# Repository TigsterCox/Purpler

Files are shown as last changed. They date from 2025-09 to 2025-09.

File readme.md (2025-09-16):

This is my first keyboard i've ever made
I do NOT reccomend you attempt building it
the current QMK firmware is built for the *BODGED* PCB whereas the KiCad files are for a *FIXED* PCB though it shouldnt be too hard of a fix

<p align="center">
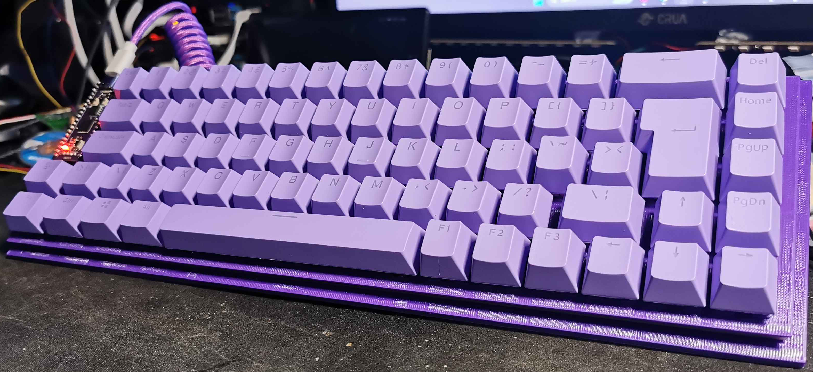
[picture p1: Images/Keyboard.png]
    
</p>

Its a 71 Key QWERTY UK ISO build based off of the Durgod Hades 69 ISO
my build uses AKKO Lavender Purple V3's and a generic keycap set from aliex
The RP2040 is a WEACT rpi 2040 as it is also purple (i think you get the theme here)
I use m2x6mm screws that are threaded into plastic, tho you can also adjust it for heatsets and shorter screws (which i plan on doing if i ever do a rebuild)

AGAIN, I DO NOT RECCOMEND BUILDING THIS

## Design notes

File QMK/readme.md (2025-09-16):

# purpler

purpler

*A short description of the keyboard/project*

* Keyboard Maintainer: [TigsterCox](https://github.com/TigsterCox)
* Hardware Supported: *The PCBs, controllers supported*
* Hardware Availability: *Links to where you can find this hardware*

Make example for this keyboard (after setting up your build environment):

    make purpler:default

Flashing example for this keyboard:

    make purpler:default:flash

See the [build environment setup](https://docs.qmk.fm/#/getting_started_build_tools) and the [make instructions](https://docs.qmk.fm/#/getting_started_make_guide) for more information. Brand new to QMK? Start with our [Complete Newbs Guide](https://docs.qmk.fm/#/newbs).

## Bootloader

Enter the bootloader in 3 ways:

* **Bootmagic reset**: Hold down the key at (0,0) in the matrix (usually the top left key or Escape) and plug in the keyboard
* **Physical reset button**: Briefly press the button on the back of the PCB - some may have pads you must short instead
* **Keycode in layout**: Press the key mapped to `QK_BOOT` if it is available

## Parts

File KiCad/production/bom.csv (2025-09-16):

Designator | Footprint | Quantity | Value | LCSC Part #
D1, D10, D11, D12, D13, D14, D15, D16, D17, D18, D19, D2, D20, D21, D22, D23, D24, D25, D26, D27, D28, D29, D3, D30, D31, D32, D33, D34, D35, D36, D37, D38, D39, D4, D40, D41, D42, D43, D44, D45, D46, D47, D48, D49, D5, D50, D51, D52, D53, D54, D55, D56, D57, D58, D59, D6, D60, D61, D62, D63, D64, D65, D66, D67, D68, D69, D7, D70, D71, D8, D9 | D_SOD-123 | 71 | Diode
S1, S10, S11, S12, S13, S15, S17, S18, S19, S2, S20, S21, S22, S23, S24, S25, S26, S27, S28, S3, S30, S32, S33, S34, S35, S36, S37, S38, S39, S4, S40, S41, S42, S43, S45, S47, S48, S49, S5, S50, S51, S52, S53, S54, S55, S56, S57, S59, S6, S60, S65, S66, S67, S68, S69, S7, S70, S8, S9 | Hotswap_MX_1.00u | 59 | Keyswitch
S14 | Hotswap_MX_2.00u | 1 | Keyswitch
S16, S44, S71 | Hotswap_MX_1.50u | 3 | Keyswitch
S29 | Hotswap_MX_ISOEnter | 1 | Keyswitch
S31, S58 | Hotswap_MX_1.75u | 2 | Keyswitch
S46, S61, S62, S63 | Hotswap_MX_1.25u | 4 | Keyswitch
S64 | Hotswap_MX_6.25u | 1 | Keyswitch
U1 | WeAct-RP2040-Pico | 1 | WeAct-RP2040-Pico

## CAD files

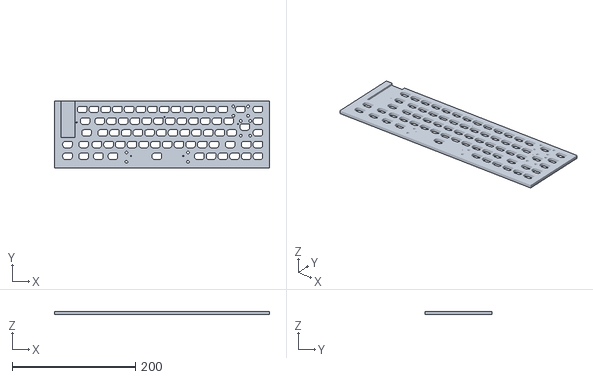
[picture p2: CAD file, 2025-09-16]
STL's/Underplate.stl
349.5 x 108.9 x 4.80

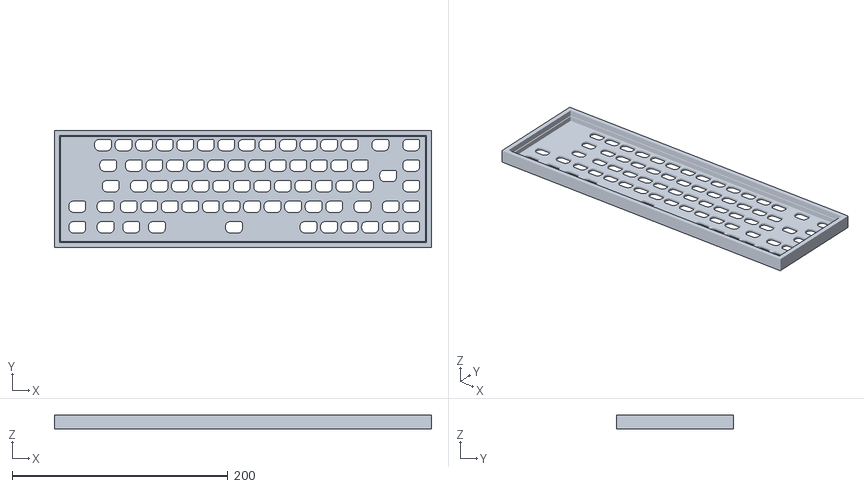
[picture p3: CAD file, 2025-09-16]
STL's/case.stl
349.5 x 108.9 x 13.1

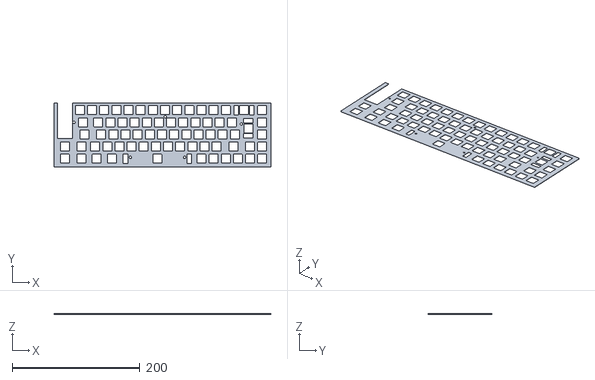
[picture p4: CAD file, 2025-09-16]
STL's/plate.stl
340.2 x 99.6 x 1.50

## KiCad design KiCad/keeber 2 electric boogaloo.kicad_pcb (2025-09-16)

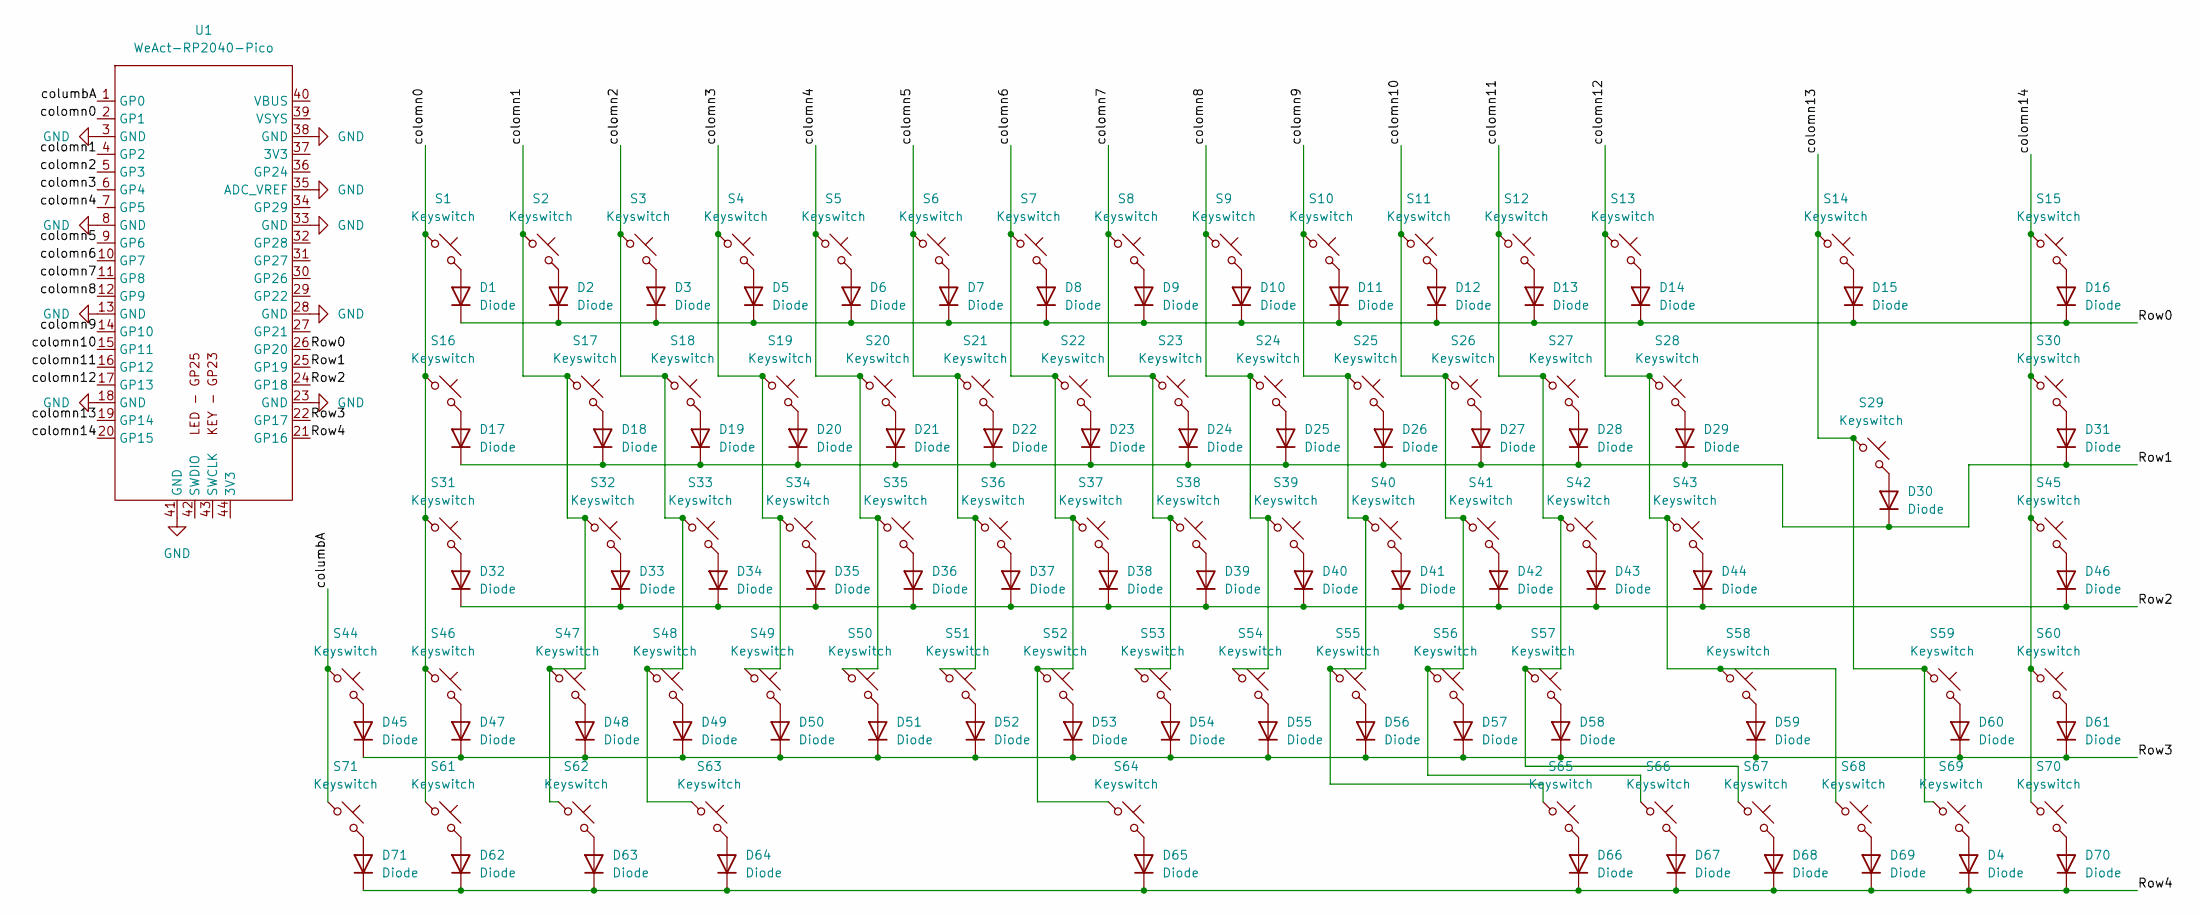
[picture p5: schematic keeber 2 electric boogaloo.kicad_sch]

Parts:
D1, D2, D3, D4, D5, D6, D7, D8, D9, D10, D11, D12, D13, D14, D15, D16, D17, D18, D19, D20, D21, D22, D23, D24, D25, D26, D27, D28, D29, D30, D31, D32, D33, D34, D35, D36, D37, D38, D39, D40, D41, D42, D43, D44, D45, D46, D47, D48, D49, D50, D51, D52, D53, D54, D55, D56, D57, D58, D59, D60, D61, D62, D63, D64, D65, D66, D67, D68, D69, D70, D71: Diode; D_SOD-123
S1, S2, S3, S4, S5, S6, S7, S8, S9, S10, S11, S12, S13, S15, S17, S18, S19, S20, S21, S22, S23, S24, S25, S26, S27, S28, S30, S32, S33, S34, S35, S36, S37, S38, S39, S40, S41, S42, S43, S45, S47, S48, S49, S50, S51, S52, S53, S54, S55, S56, S57, S59, S60, S65, S66, S67, S68, S69, S70: Keyswitch; Hotswap_MX_1.00u
S14: Keyswitch; Hotswap_MX_2.00u
S16, S44, S71: Keyswitch; Hotswap_MX_1.50u
S29: Keyswitch; Hotswap_MX_ISOEnter
S31, S58: Keyswitch; Hotswap_MX_1.75u
S46, S61, S62, S63: Keyswitch; Hotswap_MX_1.25u
S64: Keyswitch; Hotswap_MX_6.25u
U1: WeAct-RP2040-Pico

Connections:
/Row0: D1.1 (K), D2.1 (K), D3.1 (K), D5.1 (K), D6.1 (K), D7.1 (K), D8.1 (K), D9.1 (K), D10.1 (K), D11.1 (K), D12.1 (K), D13.1 (K), D14.1 (K), D15.1 (K), D16.1 (K), U1.26 (GP20)
/Row1: D17.1 (K), D18.1 (K), D19.1 (K), D20.1 (K), D21.1 (K), D22.1 (K), D23.1 (K), D24.1 (K), D25.1 (K), D26.1 (K), D27.1 (K), D28.1 (K), D29.1 (K), D30.1 (K), D31.1 (K), U1.25 (GP19)
/Row2: D32.1 (K), D33.1 (K), D34.1 (K), D35.1 (K), D36.1 (K), D37.1 (K), D38.1 (K), D39.1 (K), D40.1 (K), D41.1 (K), D42.1 (K), D43.1 (K), D44.1 (K), D46.1 (K), U1.24 (GP18)
/Row3: D45.1 (K), D47.1 (K), D48.1 (K), D49.1 (K), D50.1 (K), D51.1 (K), D52.1 (K), D53.1 (K), D54.1 (K), D55.1 (K), D56.1 (K), D57.1 (K), D58.1 (K), D59.1 (K), D60.1 (K), D61.1 (K), U1.22 (GP17)
/Row4: D4.1 (K), D62.1 (K), D63.1 (K), D64.1 (K), D65.1 (K), D66.1 (K), D67.1 (K), D68.1 (K), D69.1 (K), D70.1 (K), D71.1 (K), U1.21 (GP16)
/colomn0: S1.1, S16.1, S31.1, S46.1, S61.1, U1.2 (GP1)
/colomn1: S2.1, S17.1, S32.1, S47.1, S62.1, U1.4 (GP2)
/colomn2: S3.1, S18.1, S33.1, S48.1, S63.1, U1.5 (GP3)
/colomn3: S4.1, S19.1, S34.1, S49.1, U1.6 (GP4)
/colomn4: S5.1, S20.1, S35.1, S50.1, U1.7 (GP5)
/colomn5: S6.1, S21.1, S36.1, S51.1, U1.9 (GP6)
/colomn6: S7.1, S22.1, S37.1, S52.1, S64.1, U1.10 (GP7)
/colomn7: S8.1, S23.1, S38.1, S53.1, U1.11 (GP8)
/colomn8: S9.1, S24.1, S39.1, S54.1, U1.12 (GP9)
/colomn9: S10.1, S25.1, S40.1, S55.1, S65.1, U1.14 (GP10)
/colomn10: S11.1, S26.1, S41.1, S56.1, S66.1, U1.15 (GP11)
/colomn11: S12.1, S27.1, S42.1, S57.1, S67.1, U1.16 (GP12)
/colomn12: S13.1, S28.1, S43.1, S58.1, S68.1, U1.17 (GP13)
/colomn13: S14.1, S29.1, S59.1, S69.1, U1.19 (GP14)
/colomn14: S15.1, S30.1, S45.1, S60.1, S70.1, U1.20 (GP15)
/columbA: S44.1, S71.1, U1.1 (GP0)
GND: U1.3 (GND), U1.8 (GND), U1.13 (GND), U1.18 (GND), U1.23 (GND), U1.28 (GND), U1.33 (GND), U1.35 (ADC_VREF), U1.38 (GND), U1.41 (GND)
unnamed: D1.2 (A), S1.2
unnamed: D2.2 (A), S2.2
unnamed: D3.2 (A), S3.2
unnamed: D4.2 (A), S69.2
unnamed: D5.2 (A), S4.2
unnamed: D6.2 (A), S5.2
unnamed: D7.2 (A), S6.2
unnamed: D8.2 (A), S7.2
unnamed: D9.2 (A), S8.2
unnamed: D10.2 (A), S9.2
unnamed: D11.2 (A), S10.2
unnamed: D12.2 (A), S11.2
unnamed: D13.2 (A), S12.2
unnamed: D14.2 (A), S13.2
unnamed: D15.2 (A), S14.2
unnamed: D16.2 (A), S15.2
unnamed: D17.2 (A), S16.2
unnamed: D18.2 (A), S17.2
unnamed: D19.2 (A), S18.2
unnamed: D20.2 (A), S19.2
unnamed: D21.2 (A), S20.2
unnamed: D22.2 (A), S21.2
unnamed: D23.2 (A), S22.2
unnamed: D24.2 (A), S23.2
unnamed: D25.2 (A), S24.2
unnamed: D26.2 (A), S25.2
unnamed: D27.2 (A), S26.2
unnamed: D28.2 (A), S27.2
unnamed: D29.2 (A), S28.2
unnamed: D30.2 (A), S29.2
unnamed: D31.2 (A), S30.2
unnamed: D32.2 (A), S31.2
unnamed: D33.2 (A), S32.2
unnamed: D34.2 (A), S33.2
unnamed: D35.2 (A), S34.2
unnamed: D36.2 (A), S35.2
unnamed: D37.2 (A), S36.2
unnamed: D38.2 (A), S37.2
unnamed: D39.2 (A), S38.2
unnamed: D40.2 (A), S39.2
unnamed: D41.2 (A), S40.2
unnamed: D42.2 (A), S41.2
unnamed: D43.2 (A), S42.2
unnamed: D44.2 (A), S43.2
unnamed: D45.2 (A), S44.2
unnamed: D46.2 (A), S45.2
unnamed: D47.2 (A), S46.2
unnamed: D48.2 (A), S47.2
unnamed: D49.2 (A), S48.2
unnamed: D50.2 (A), S49.2
unnamed: D51.2 (A), S50.2
unnamed: D52.2 (A), S51.2
unnamed: D53.2 (A), S52.2
unnamed: D54.2 (A), S53.2
unnamed: D55.2 (A), S54.2
unnamed: D56.2 (A), S55.2
unnamed: D57.2 (A), S56.2
unnamed: D58.2 (A), S57.2
unnamed: D59.2 (A), S58.2
unnamed: D60.2 (A), S59.2
unnamed: D61.2 (A), S60.2
unnamed: D62.2 (A), S61.2
unnamed: D63.2 (A), S62.2
unnamed: D64.2 (A), S63.2
unnamed: D65.2 (A), S64.2
unnamed: D66.2 (A), S65.2
unnamed: D67.2 (A), S66.2
unnamed: D68.2 (A), S67.2
unnamed: D69.2 (A), S68.2
unnamed: D70.2 (A), S70.2
unnamed: D71.2 (A), S71.2

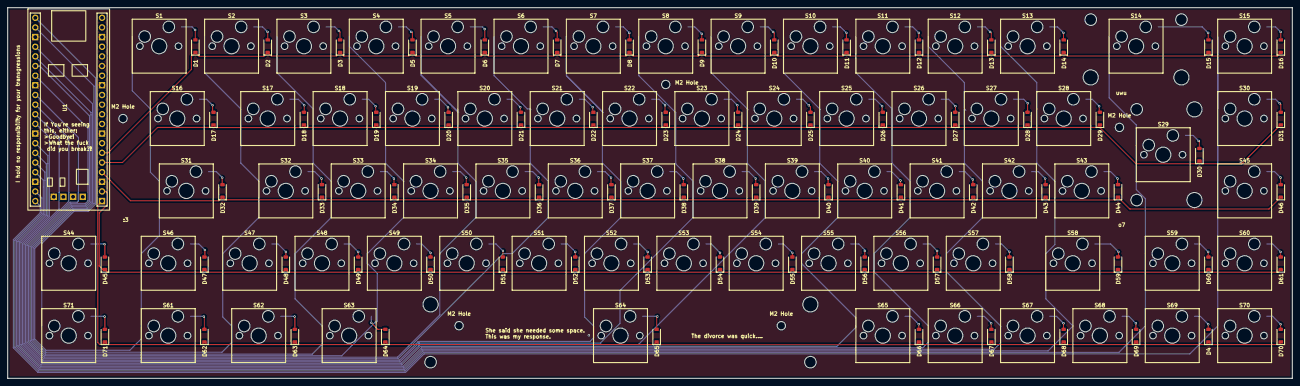
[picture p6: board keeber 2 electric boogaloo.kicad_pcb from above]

Board: 2 copper layers, 338.2 x 97.6 mm, 148 parts (0 on the bottom side), 93 nets.

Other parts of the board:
M2 Hole, M2 Hole#2, M2 Hole#3, M2 Hole#4, M2 Hole#5: MountingHole_2.2mm_M2
